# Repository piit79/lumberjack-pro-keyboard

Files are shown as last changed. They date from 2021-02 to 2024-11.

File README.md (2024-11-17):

# Lumberjack Pro - Hotswap ortholinear 60% keyboard PCB based on the Frood/nice!nano

Lumberjack is a hotswap split 5x12 ortholinear keyboard PCB based on the Frood or nice!nano controllers, and using mostly through-hole components.

The goal of this project is to build a hotswap ortholinear PCB that fits in many standard 60% tray mount cases.

Inspired by the [Plaid keyboard](https://github.com/hsgw/plaid).

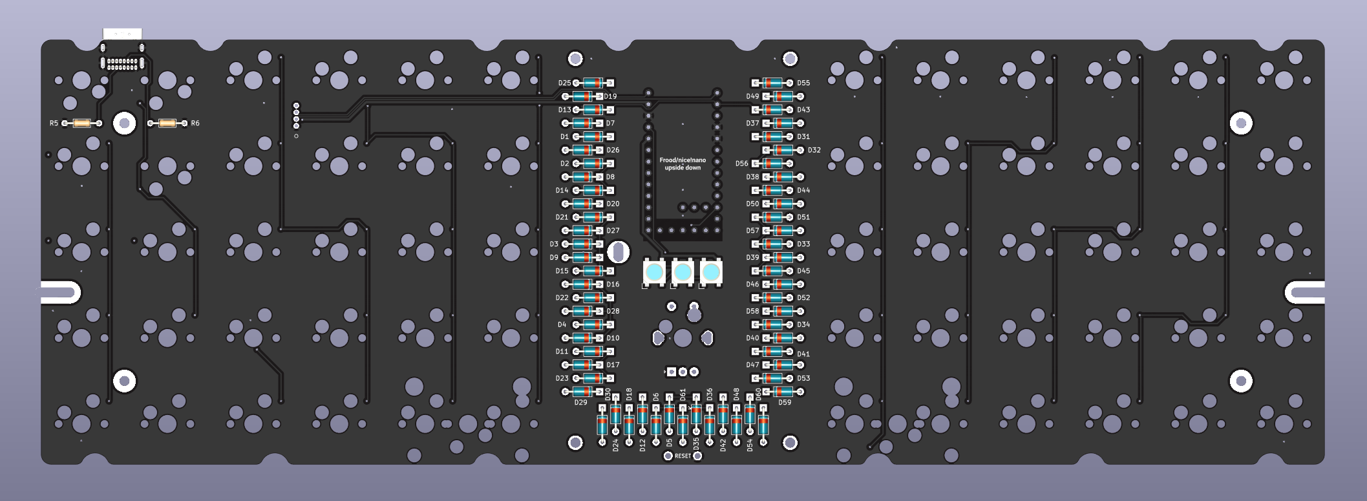
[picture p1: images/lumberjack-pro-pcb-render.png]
PCB render


* Designed to be easy to build with minimal soldering experience
* Uses either the modern [Frood](https://42keebs.eu/shop/parts/controllers/frood-rp2040-pro-micro-controller/) (wired) or [nice!nano](https://nicekeyboards.com/nice-nano) (wireless) controllers instead of the old-school 8bit ATmega MCU
* Uses Kailh hotswap sockets for easy switch swaps
* Get that visible component aesthetic in a standard 60% tray-mount case
* Supports both USB Mini and USB-C
* Plateless or with FR4 switch plates

# Kit availability

Complete kits can be purchased at [42. Keebs](https://42keebs.eu/shop/kits/pro-micro-based/lumberjack-pro-hotswap-50-ortho-kit/)

# Ordering parts

See the [Bill of materials](BOM.md) for a detailed list of the required parts.

PCBs can be manufactuered by a variety of online PCB fabricators. You can use [PCBShopper](https://pcbshopper.com/) to search for the best price.

The [zip file in the releases](https://github.com/piit79/lumberjack-pro-keyboard/releases) contains the gerber files your fabricator will need to make the PCB.

When uploading the gerber zip files, use the default PCB settings.

Note that when uploading to JLCPCB, the upload tool may not detect the dimensions of the PCB from the gerber files and may not generate a preview image. This appears to be an issue with JLCPCB and you can manually enter the PCB size as 94.6x285mm.

If you want to use a plate, there are gerbers for an FR4 plate. You will need two plates, one for each half of the keyboard.

# Construction

Solder all the components onto the top side of the PCB except the USB connector which should be on the back of the board. Leave the larger components until last so that the board will lie flat upsidedown while you solder the resistors and capacitors.

Ensure that the diodes are installed in the correct orientation. The square pad is for the side with the black stripe.

See [the build guide](guide.md) for more information.

## Need help?

Have questions or need help, reach out via the [42. Keebs Discord server](https://42keebs.eu/discord) where you will find many helpful Lumberjack owners.

# Firmware

Firmware is available in our [QMK/Vial fork](https://github.com/piit79/vial-qmk/tree/vial/keyboards/42keebs/lumberjack_pro).

Follow the [QMK firmware instructions](https://docs.qmk.fm/#/flashing) to build and flash the firmware.

To put the controller into bootloader mode so it is ready to recieve firmware, do the following:

* A brand new Frood and nice!nano will enter bootloader mode automatically
* On the Frood, hold the BOOT button while pressing the RESET button
* If the Frood is flashed with a QMK/Vial firmware, double-press the RESET button quickly
* On the nice!nano, double-press the RESET button quickly

Once the controller enters the bootloader mode, it will present itself as a USB mass storage device ("USB flash drive"). To flash the firmware .uf2 file, simply copy it to the drive.

# Component cover

Cut a piece of 2mm thick acrylic to size (95x57mm) and drill 4 m2 holes in the corners for the standoffs. Use the PCB or cover.dxf as a guide for the hole positions, you can also use cover.dxf for laser cutting the correct size acrylic.

Affix the 4 standoffs to the PCB with screws from underneath the PCB. Use the remaining 4 screws to attach the acrylic to the top of the standoffs.

# Revisions

## Rev1

* Initial revision using hotswap sockets with support for both Frood and nice!nano controllers

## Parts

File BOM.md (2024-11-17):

# Bill of Materials (BOM)

| Ref | Qty | Value or Part# | Description |
|---|---|---|---|
| U1 | 0-1 | Frood | Frood RP2040-based controller |
| U1 | 0-1 | nice!nano | nice!nano wireless controller |
| D1-61 | 61 | 1N4148 | generic switching diode |
| MX1-61 | 60-61 | CPG-1511 | Kailh MX hotswap socket |
| SW1-61 | 60-61 | MX | Cherry MX-compatible keyboard switch |
| EC11 | 0-1 | EC11 | EC11 rotary encoder (optional, instead of switch #61) |
| RGB1-3 | 3 | WS2812B/SK6812 | WS2812B-compatible 5x5 mm RGB module (optional) |
| J1 | 1 | USB4085-GF-A | USB-C socket (only used with the Frood controller) |
| J3 | 1 | SM04B-SRSS-TB  | JST SH SMD socket, 1.5 mm pitch (optional for daughterboard) |
| J4 | 1 | S4B-ZR | JST ZH right-angle THT socket, 1.5 mm pitch (optional for daughterboard) |
| R5,R6 | 2 | 5.1 kΩ | 1/8 W resistor (only needed with Frood and USB-C) |
| SW1 | 1 | 6x3 mm | tactile micro switch |
| cover | 1 | 95x57x2 mm | 2 mm acrylic component cover |
| screw | 8 | M2x4 mm | screws to mount the cover |
| standoff  | 4 | M2x10 mm | standoffs for component cover |

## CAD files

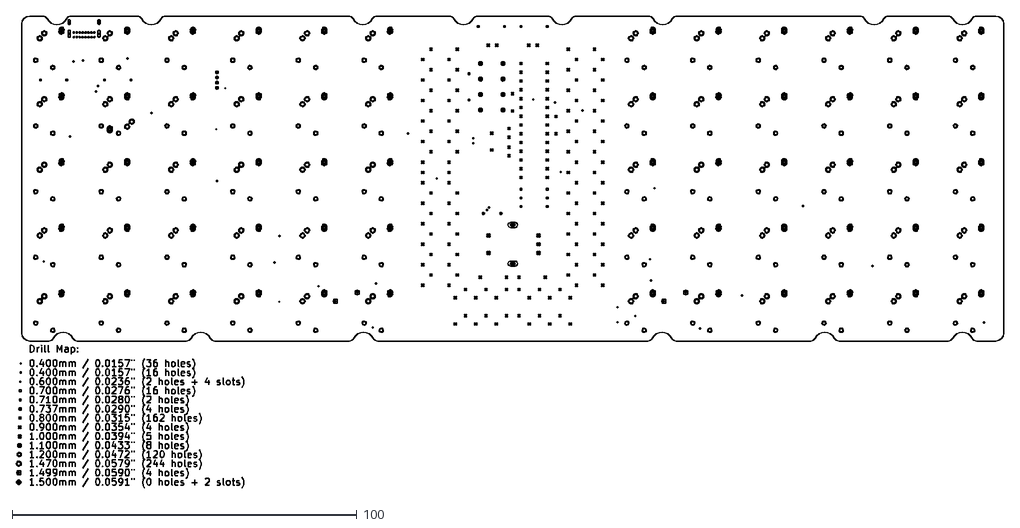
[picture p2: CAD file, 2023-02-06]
gerbers/lumberjack-PTH-drl_map.dxf
286.3 x 136.8

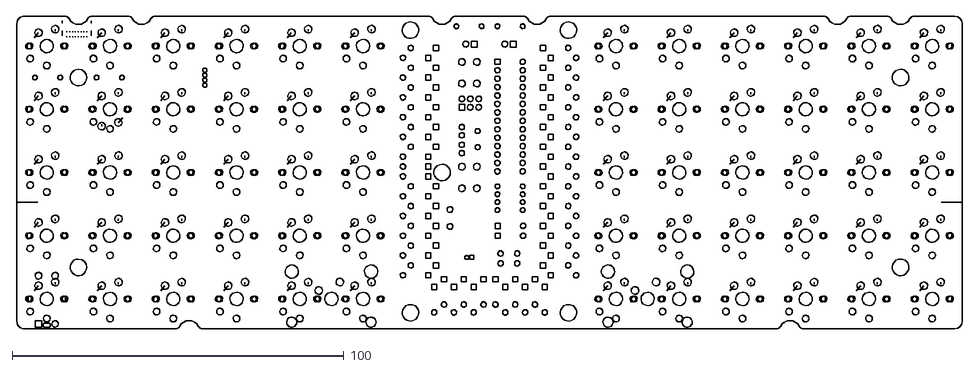
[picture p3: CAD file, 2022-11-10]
lumberjack-brd.dxf
285.2 x 94.2

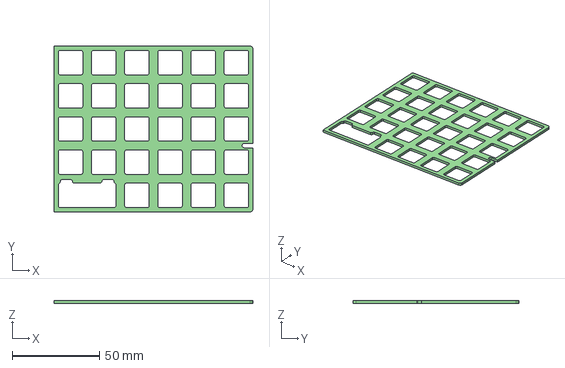
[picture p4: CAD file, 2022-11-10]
plates/mx/lumberjack-split.step
114.3 x 95.3 x 1.60 mm

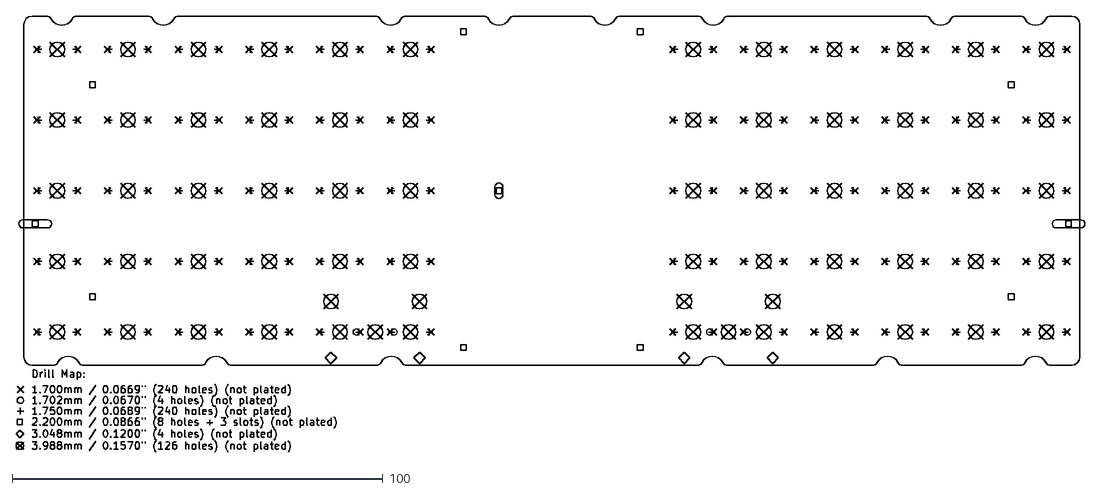
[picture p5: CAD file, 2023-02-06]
gerbers/lumberjack-NPTH-drl_map.dxf
288.2 x 117.5

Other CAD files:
lumberjack-pcb.dxf

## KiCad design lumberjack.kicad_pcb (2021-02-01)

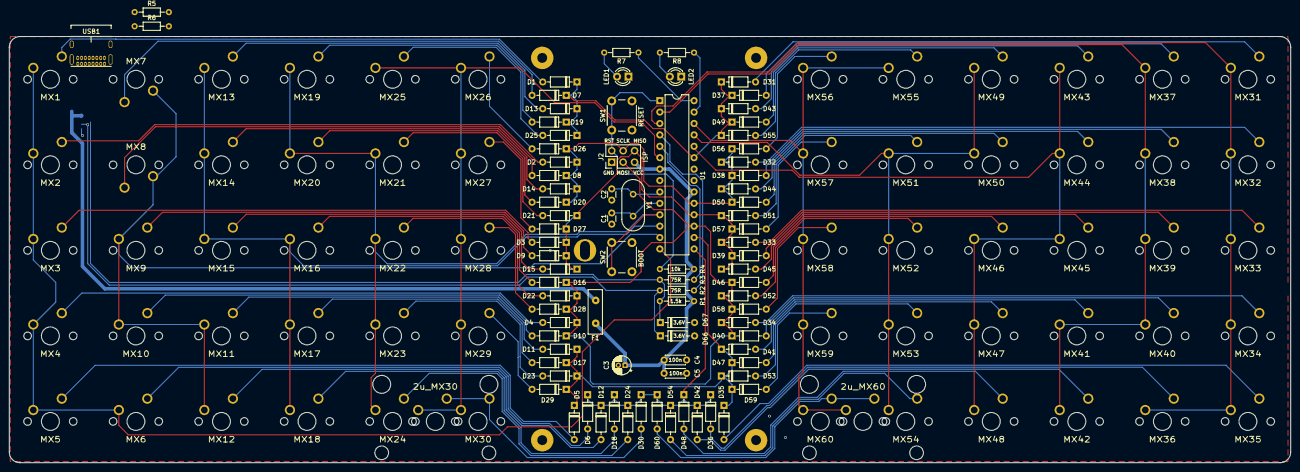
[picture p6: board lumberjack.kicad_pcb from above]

Board: 2 copper layers, 285.4 x 94.9 mm, 154 parts (1 on the bottom side), 92 nets.

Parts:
2u_MX30, 2u_MX60: SW_Push; MX_PCB_200B
C1, C2: 22p; C_Disc_D3.0mm_W1.6mm_P2.50mm
C3: 4.7u; CP_Radial_D4.0mm_P1.50mm
C4, C5: 100n; C_Disc_D4.3mm_W1.9mm_P5.00mm
D1, D2, D3, D4, D5, D6, D7, D8, D9, D10, D11, D12, D13, D14, D15, D16, D17, D18, D19, D20, D21, D22, D23, D24, D25, D26, D27, D28, D29, D30, D31, D32, D33, D34, D35, D36, D37, D38, D39, D40, D41, D42, D43, D44, D45, D46, D47, D48, D49, D50, D51, D52, D53, D54, D55, D56, D57, D58, D59, D60: 1N4148; D_DO-35_SOD27_P7.62mm_Horizontal
D66, D67: 3.6V; D_DO-35_SOD27_P7.62mm_Horizontal
F1: 100mA; Fuse_Bourns_MF-RHT100
H1, H2, H3, H4: M2; MountingHole_M2
H5, H6, H7: M2; MountingSlot_M2
J2: AVR_ISP_6; PinHeader_2x03_P2.54mm_Vertical
J3: JST; JST_SH_SM04B-SRSS-TB_1x04-1MP_P1.00mm_Horizontal
LED1: RED; LED_D3.0mm
LED2: GREEN; LED_D3.0mm
MX1, MX2, MX3, MX4, MX5, MX6, MX7, MX8, MX9, MX10, MX11, MX12, MX13, MX14, MX15, MX16, MX17, MX18, MX19, MX20, MX21, MX22, MX23, MX24, MX25, MX26, MX27, MX28, MX29, MX30, MX31, MX32, MX33, MX34, MX35, MX36, MX37, MX38, MX39, MX40, MX41, MX42, MX43, MX44, MX45, MX46, MX47, MX48, MX49, MX50, MX51, MX52, MX53, MX54, MX55, MX56, MX57, MX58, MX59, MX60: SW_Push; MX
R1, R7, R8: 1.5k; R_Axial_DIN0204_L3.6mm_D1.6mm_P7.62mm_Horizontal
R2, R3: 75R; R_Axial_DIN0204_L3.6mm_D1.6mm_P7.62mm_Horizontal
R4: 10k; R_Axial_DIN0204_L3.6mm_D1.6mm_P7.62mm_Horizontal
R5, R6: 5.1k; R_Axial_DIN0204_L3.6mm_D1.6mm_P7.62mm_Horizontal
SW1: RESET; SW_PUSH_6mm
SW2: BOOT; SW_PUSH_6mm
U1: ATMEGA328-PU; DIP-28_W7.62mm
USB1: Type-C_USB_C_GCT_USB4085; USB_C_GCT_USB4085
Y1: 16MHz; Crystal_HC49-4H_Vertical

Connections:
+5V: C3.1, C4.1, C5.1, F1.2, J2.5, R1.2, R4.1, U1.7, U1.20
/COL0: MX1.2, MX2.2, MX3.2, MX4.2, MX5.2, MX6.2, U1.14
/COL1: MX7.2, MX8.2, MX9.2, MX10.2, MX11.2, MX12.2, U1.13
/COL2: MX13.2, MX14.2, MX15.2, MX16.2, MX17.2, MX18.2, U1.12
/COL3: MX19.2, MX20.2, MX21.2, MX22.2, MX23.2, MX24.2, SW2.1, U1.11
/COL4: 2u_MX30.2, MX25.2, MX26.2, MX27.2, MX28.2, MX29.2, MX30.2, U1.6
/COL5: MX31.2, MX32.2, MX33.2, MX34.2, MX35.2, MX36.2, U1.3
/COL6: MX37.2, MX38.2, MX39.2, MX40.2, MX41.2, MX42.2, U1.2
/COL7: MX43.2, MX44.2, MX45.2, MX46.2, MX47.2, MX48.2, U1.24
/COL8: MX49.2, MX50.2, MX51.2, MX52.2, MX53.2, MX54.2, U1.25
/COL9: 2u_MX60.2, MX55.2, MX56.2, MX57.2, MX58.2, MX59.2, MX60.2, U1.26
/LED1: R7.1, U1.28
/LED2: R8.1, U1.27
/RESET: J2.2, R4.2, SW1.1, U1.1
/ROW0: D1.1, D7.1, D13.1, D19.1, D25.1, D31.1, D37.1, D43.1, D49.1, D55.1, U1.23
/ROW1: D2.1, D8.1, D14.1, D20.1, D26.1, D32.1, D38.1, D44.1, D50.1, D56.1, J2.4, U1.19
/ROW2: D3.1, D9.1, D15.1, D21.1, D27.1, D33.1, D39.1, D45.1, D51.1, D57.1, J2.6, U1.18
/ROW3: D4.1, D10.1, D16.1, D22.1, D28.1, D34.1, D40.1, D46.1, D52.1, D58.1, J2.3, U1.17
/ROW4: D5.1, D11.1, D17.1, D23.1, D29.1, D35.1, D41.1, D47.1, D53.1, D59.1, U1.16
/ROW5: D6.1, D12.1, D18.1, D24.1, D30.1, D36.1, D42.1, D48.1, D54.1, D60.1, U1.15
/USB_D+: R2.1, U1.4
/USB_D-: R3.1, U1.5
GND: C1.2, C2.2, C3.2, C4.2, C5.2, D66.2, D67.2, J2.1, J3.4, LED1.1, LED2.1, R5.1, R6.1, SW1.2, SW2.2, U1.8, U1.22, USB1.A1, USB1.A12, USB1.B1, USB1.B12, USB1.S1
unnamed: 2u_MX30.1, D30.2, MX30.1
unnamed: 2u_MX60.1, D60.2, MX60.1
unnamed: C1.1, U1.10, Y1.2
unnamed: C2.1, U1.9, Y1.1
unnamed: D1.2, MX1.1
unnamed: D2.2, MX2.1
unnamed: D3.2, MX3.1
unnamed: D4.2, MX4.1
unnamed: D5.2, MX5.1
unnamed: D6.2, MX6.1
unnamed: D7.2, MX7.1
unnamed: D8.2, MX8.1
unnamed: D9.2, MX9.1
unnamed: D10.2, MX10.1
unnamed: D11.2, MX11.1
unnamed: D12.2, MX12.1
unnamed: D13.2, MX13.1
unnamed: D14.2, MX14.1
unnamed: D15.2, MX15.1
unnamed: D16.2, MX16.1
unnamed: D17.2, MX17.1
unnamed: D18.2, MX18.1
unnamed: D19.2, MX19.1
unnamed: D20.2, MX20.1
unnamed: D21.2, MX21.1
unnamed: D22.2, MX22.1
unnamed: D23.2, MX23.1
unnamed: D24.2, MX24.1
unnamed: D25.2, MX25.1
unnamed: D26.2, MX26.1
unnamed: D27.2, MX27.1
unnamed: D28.2, MX28.1
unnamed: D29.2, MX29.1
unnamed: D31.2, MX31.1
unnamed: D32.2, MX32.1
unnamed: D33.2, MX33.1
unnamed: D34.2, MX34.1
unnamed: D35.2, MX35.1
unnamed: D36.2, MX36.1
unnamed: D37.2, MX37.1
unnamed: D38.2, MX38.1
unnamed: D39.2, MX39.1
unnamed: D40.2, MX40.1
unnamed: D41.2, MX41.1
unnamed: D42.2, MX42.1
unnamed: D43.2, MX43.1
unnamed: D44.2, MX44.1
unnamed: D45.2, MX45.1
unnamed: D46.2, MX46.1
unnamed: D47.2, MX47.1
unnamed: D48.2, MX48.1
unnamed: D49.2, MX49.1
unnamed: D50.2, MX50.1
unnamed: D51.2, MX51.1
unnamed: D52.2, MX52.1
unnamed: D53.2, MX53.1
unnamed: D54.2, MX54.1
unnamed: D55.2, MX55.1
unnamed: D56.2, MX56.1
unnamed: D57.2, MX57.1
unnamed: D58.2, MX58.1
unnamed: D59.2, MX59.1
unnamed: D66.1, J3.3, R2.2, USB1.A6, USB1.B6
unnamed: D67.1, J3.2, R1.1, R3.2, USB1.A7, USB1.B7
unnamed: F1.1, J3.1, USB1.A4, USB1.A9, USB1.B4, USB1.B9
unnamed: LED1.2, R7.2
unnamed: LED2.2, R8.2
unnamed: R5.2, USB1.A5
unnamed: R6.2, USB1.B5

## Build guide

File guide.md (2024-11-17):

# Lumberjack Pro - Kit assembly guide

This assembly guide will guide you through putting together your Lumberjack Pro keyboard PCB kit. The process is quite simple with only basic soldering experience required.

⚠️ Please note this guide was adapted for the Lumberjack Pro from the original build guide and some pictures have not been update yet.

## Before starting

* Check you have all the required items not included in the kit.
    * Soldering iron
    * Solder
    * Flush cutters
    * 60-61 MX key switches
* Check that you have all the components. See [BOM](BOM.md)
* If you are not used to soldering, learn how to solder components.
    * https://learn.adafruit.com/adafruit-guide-excellent-soldering/tools

## Soldering

### Controller considerations

The PCB supports either the Frood controller (wired only), or the nice!nano wireless controller.

#### Frood

When using the Frood, install the on-board USB-C socket that is positioned to fit many cases, or a USB-C daughterboard.

#### nice!nano

* You can make your Lumberjack Pro wireless using teh nice!nano controller
* A 1S (3.7 V) Li-Po battery can be connected to the JST socket pads marked "B+/B-"
  * There is currently no power switch on the PCB, so the controller will be permanently powered. However, this is not really an issue because the controller is very power efficient and enters a sleep mode after a short while, and you can use a sizeable battery with the Lumberjack Pro
  * The battery can only be charged via the USB-C socket on the nice!nano, which might be a bit difficult due to the position of the controller
* ⚠️ **DO NOT** fit the USB-C socket or a daughterboard when using the nice!nano with a battery! ⚠️
  * nice!nano doesn't have the USB data lines broken out, so the wired communication will not work (although the controller itself can be powered from the USB-C socket or the daughterboard)
  * ⚠️ The battery connected to the JST socket pads would be connected directly to the USB 5 V supply and could be overcharged easily and quickly, potentially leading to a fire! ⚠️

### USB socket (J1)

First you will solder the USB connector to the **underside** of the PCB. All other components (except the JST sockets) go on the top.

Due to the small size of the pins on the connector you might want to use a different soldering technique called drag soldering. You will need a separate supply of flux to do this, either liquid flux or a flux pen. However, with a suitable soldering iron tip the pins can be soldered traditionally as well.

* Insert the USB connector into the board.
* Flip the board over and solder one of the legs into place.
* Reheat the pad and press the USB port firmly into place to ensure it sits flat before then soldering the other 3 legs.
* Apply no-clean flux across all of the small pins.
* Apply a small amount of solder to your iron and drag it across the pins, repeat until all holes are filled with solder.
* The flux will cause the solder to flow to the pins and avoid creating solder bridges between the pins.
* Add more flux as needed as you go along.
* Use your iron between the pads to remove any solder bridges.
* Check the solder joints carefully, under a magnifying glass if needed, to ensure there are no bridges between pads.

Remember to also install the two extra resistors (R5 & R6).

USB-C

If you have a multimeter you can use it to check for bridges, put it into continuity mode and check that the following pins connect to each other and all others do not:

* Top 1 & 8, bottom 1 & 8 are ground pins and should all connect to each other and the square ground pad of the USB-mini footprint.
* Top 2 & 7, bottom 2 & 7 are V+ pins and should all connect to each other and the round bottom left pad of the USB-mini.
* Top 4 & bottom 5 are D- pins and should connect to top left pad of the USB-mini.
* Top 5 & bottom 4 are D+ pins and should connect to bottom center pad of the USB-mini.
* Bottom 3 is the CC1 pin and should connect to the top pad of the R5 resistor.
* Top 6 is the CC2 pin and should connect to the top pad of the R6 resistor.

#### JST connector (J3,4)

If you want to use a daughterboard instead of a USB connector, there are footprints for both a SMD or a THT connector. The connectors are positioned between the top and second row of switches so as to fall within the cable gutter of cases such as the Bakeneko, be aware that this might not be a suitable position for all cases.

Note: A JST connector is not included in the Lumberjack kit, the SMD variant is part JST-SR-4 and for THT it is S4B-ZR.

### Resistors for USB-C (R5,6)

If you are using a UCB-C connector you will need to solder these extra two resistors. They are marked in the kit with a black dot on the paper to help distingish them from the other resistors.

* R5,6: 5.1kΩ Green, brown, black, brown, red

### Hotswap sockets

* To solder the hotswap sockets, first put a healthy amount of solder on one of the pads of each socket footprint
* Then put the sockets into place over the solder
* Reheat the solder under the socket contact and gently push the socket down into the molten solder using a pair of tweezers
* To avoid creating a cold joint, keep heating for a second maintaining contact with the socket contact, then keep holding the socket in place while the solder solidifies. Avoid blowing on the solder to speed up the cooling
* Add solder to the other contact of each hotswap socket. Make sure to use enough heat so that the solder flows into the joint instead of just inside the contact

### Diodes 1N4148 (D1-61)

Solder the diodes.

Diodes are a polarized component and therefore take care of direction, the black line on the diode is the cathode and goes in the square pad on PCB.

### Tactile switch (SW1)

Push the switches into the PCB and solder the legs.

### Firmware

Follow the [QMK firmware instructions](https://docs.qmk.fm/#/flashing) to build and flash the firmware.

`qmk compile -kb 42keebs/lumberjack_pro -km vial`

### Check list

Now the board should be fully functional, so check that everything works before adding the switches.

Plug in the PCB and use a pair of tweezers or a piece of wire to check each keyswitch pad triggers a keypress.

## Switches

### Stabilizers

If you are using 2u keys and want to use key stabilizers, fix them to the board before inserting the switches.

If you are using screw in stabilizers, be aware that the screws can cause a short to the unused switch pads for the 1u keys. To avoid this, use plastic washers or electrical tape under the screws to isolate them from the PCB.

### Trim switch legs

When fitting key switches, the switches at the 'Q' and 'P' positions on the 2nd row will fowl on the standoffs in your keyboard case, so you need to trim down one of the stabilizing pins and part of the center pin to ensure the PCB fits flush within the case.

Switch legs

If you are using a 2u key on the right hand side, you will also need to trim down the center pin so that it does not fowl on the standoff. The position the case standoffs will be is marked on the soldermask of the underside of the PCB.

Switch center pin

### Insert switches

Insert the switches into the hotswap sockets in the PCB.

If you are using a plate, insert the switches through the plate.

Note also that the switch at the 'Q' position is upside down so that the switch pins do not interfere with the case standoff. So are switches in the Esc/Grave and 1 positions to avoid interference with the USB-C socket.

## Component cover

Affix the 4 standoffs to the PCB with screws from underneath the PCB. Use the remaining 4 screws to attach the acrylic to the top of the standoffs.

Do not overtighten the screws as this could crack the acrylic.

## Case fitting

When fixing the PCB to your case you will only use the center, the left and the right screw holes. Depending on your case design, the PCB will be supported by the other standoffs.

## The End

Congratulations, your build is complete.

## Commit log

2022-03-31 Switch to USB-C socket only for better alignment
    NB., gerber files have not been updated.
2022-03-31 Add support for an optional rotary encoder in the bottom left position
    [lumberjack-B_Cu.gbr, lumberjack-B_Mask.gbr, lumberjack-B_Paste.gbr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]
2022-03-31 Improve MX split plate: rounded corners, small slot
    [lumberjack-split-B_Cu.gbl, lumberjack-split-B_Mask.gbs, lumberjack-split-B_Paste.gbp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]
2022-11-10 WIP: PCB drawings, split plates
    [lumberjack-brd.dxf, lumberjack-pcb.dxf, lumberjack-split.step]
2023-02-01 Drop USB Mini support for better USB-C socket alignment
    [lumberjack.kicad_sch]
2023-02-02 Improve crystal ground loop to reduce RFI
2023-02-06 Add rotary encoder support; fix DRC errors
    [lumberjack.kicad_sch]
2023-02-06 Update gerber files
    [lumberjack-B_Cu.gbr, lumberjack-B_Mask.gbr, lumberjack-B_Paste.gbr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]
2023-07-12 Update the gerber zip and plate
2024-05-31 Rename project files to lumberjack-pro-frood
    [lumberjack-pro-frood.kicad_sch, lumberjack.kicad_sch]
2024-05-31 Add 42. Keebs KiCad library
2024-05-31 WIP: replace discrete MCU with the Frood
    [lumberjack-pro-frood.kicad_sch]
2024-06-02 Update the 42. Keebs KiCad library
2024-11-17 Use smaller cover mounting holes
2024-11-17 Update README, BOM and guide
